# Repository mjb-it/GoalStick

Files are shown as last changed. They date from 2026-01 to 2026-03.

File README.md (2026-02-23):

# GoalStick

An NHL goal celebration system that triggers LED light shows when your favorite team scores. The system consists of three components:

- **Raspberry Pi Service** (Python) - Monitors NHL games and detects goals
- **Android App** (Kotlin) - Companion app for configuration via Bluetooth
- **ESP32 Firmware** (Arduino/C++) - Controls WS2812B LED strip animations

## Repository Structure

```
GoalStick/
├── PythonSrc/       # Raspberry Pi Python service
├── Android/         # Android companion app
├── ESP32/           # ESP32 LED controller firmware
├── Makefile         # Build and test automation
└── README.md
```

---

# Raspberry Pi Service (Python)

The core service that monitors NHL games and communicates with the ESP32 to trigger celebrations.

## Requirements

- Raspberry Pi Zero 2 W (or any Pi with GPIO)
- Python 3.9+
- Serial connection to ESP32

## Installation

```bash
cd PythonSrc
pip install -e .
```

Or using Make:
```bash
make python-install
```

## Usage

```bash
cd PythonSrc

# Start the goal monitoring service
python main.py

# Set your team (persists across reboots)
python main.py --team WSH

# Show currently configured team
python main.py --show-team

# Enter Bluetooth pairing mode
python main.py --pair
```

## Testing

```bash
# Run unit tests (69 tests)
make python-test

# Run with coverage report
make python-test-cov
```

## Configuration Options

| Parameter | Type | Default | Description |
|---|---|---|---|
| `team_abbr` | str | "WSH" | NHL team abbreviation |
| `check_interval` | float | 2.0 | Seconds between goal checks during live games |
| `daily_check_hour` | int | 8 | Hour (24-hour format) to check daily schedule |
| `pre_game_wake_minutes` | int | 5 | Minutes before game to wake up |
| `serial_port` | str | "/dev/serial0" | Serial port for ESP32 communication |
| `serial_baud_rate` | int | 115200 | Baud rate for serial communication |
| `pairing_button_pin` | int | 17 | BCM GPIO pin for pairing button |
| `esp32_reset_pin` | int | 27 | BCM GPIO pin connected to ESP32 EN |

## Dependencies

- `nhlpy` - NHL API client
- `python-dateutil` - Date parsing utilities
- `pyserial` - Serial communication with ESP32
- `RPi.GPIO` - GPIO control (optional, for button/reset)

---

# Android App (Kotlin)

Companion app for configuring the GoalStick via Bluetooth.

## Requirements

- Android Studio Hedgehog (2023.1.1) or newer
- Android SDK 34
- Java 17 (for command-line builds)

## Features

- Bluetooth device discovery and pairing
- WiFi credential configuration
- NHL team selection (all 32 teams)
- Send configuration to Raspberry Pi

## Building

### Using Android Studio (Recommended)

1. Open `Android/` folder in Android Studio
2. Sync Gradle files
3. Build → Build Bundle(s) / APK(s) → Build APK(s)

### Using Command Line

```bash
# Requires Android SDK and Java 17
make android-build

# APK location:
# Android/app/build/outputs/apk/debug/app-debug.apk
```

### Installing on Device

```bash
# With device connected via USB
make android-install

# Or manually:
adb install Android/app/build/outputs/apk/debug/app-debug.apk
```

## Project Structure

```
Android/
├── app/src/main/
│   ├── java/com/goalstick/android/
│   │   ├── MainActivity.kt           # Main UI
│   │   ├── bluetooth/BluetoothManager.kt  # BT connection
│   │   ├── data/ConfigurationData.kt # Team data
│   │   └── ui/                        # UI components
│   ├── res/layout/                    # XML layouts
│   └── AndroidManifest.xml
├── build.gradle
└── settings.gradle
```

---

# ESP32 Firmware (Arduino)

Controls the WS2812B LED strip and receives commands from the Raspberry Pi.

## Requirements

- ESP32 development board
- Arduino IDE or PlatformIO
- FastLED library

## Building

1. Open `ESP32/hockey_stick_light_controller.ino` in Arduino IDE
2. Install FastLED library (Sketch → Include Library → Manage Libraries)
3. Select board: ESP32 Dev Module
4. Upload to ESP32

## Pin Configuration

| Pin | Function |
|-----|---|
| GPIO 4 | LED Data Out |
| GPIO 16 (RX2) | Serial RX from Raspberry Pi |
| GPIO 17 (TX2) | Serial TX to Raspberry Pi |

## Serial Protocol

The ESP32 listens on Serial2 at 115200 baud:

| Command | Format | Description |
|---|---|---|
| Celebrate | `C:RRGGBB,RRGGBB,...\n` | Trigger goal animation with hex colors |
| Idle | `I\n` | Stop animation and clear strip |
| Ping | `P\n` | Health check, responds with `PONG\n` |

Example: `C:FFFFFF,002D62,E51937\n` (Washington Capitals colors)

---

# Hardware Setup

## Components

- **Raspberry Pi Zero 2 W** - Runs the Python service
- **ESP32** - Controls LED strip via serial
- **WS2812B LED Strip** - 300+ addressable LEDs
- **5V Power Supply** - Minimum 2A (more for full strip)
- **Momentary Push Button** - For Bluetooth pairing

## Wiring Diagram

### Raspberry Pi ↔ ESP32

| Raspberry Pi | ESP32 | Purpose |
|---|---|---|
| GPIO 14 (TX) | GPIO 16 (RX2) | Serial data |
| GPIO 27 | EN | ESP32 reset (optional) |
| GND | GND | Common ground |

### ESP32 ↔ LED Strip

| ESP32 | LED Strip | Purpose |
|---|---|---|
| GPIO 4 | Data In (via 470Ω resistor) | LED control |
| VIN | 5V | Power |
| GND | GND | Ground |

### Pairing Button

| Raspberry Pi | Button |
|---|---|
| GPIO 17 | Pin 1 (uses internal pull-up) |
| GND | Pin 2 |

Press and hold for 3 seconds to enter pairing mode.

## Hardware Protection

- **1000µF Capacitor** - Across 5V/GND rails near power input
- **470Ω Resistor** - Between ESP32 GPIO 4 and LED Data In
- **Logic Level Shifter** (optional) - 74AHCT125 for long cable runs

---

# Build & Deployment

For hands-free installation and automated deployment instructions, see **[DEPLOYMENT.md](DEPLOYMENT.md)**.

Quick build commands:

```bash
make help          # Show all available targets
make all           # Build everything
make test          # Run all tests
make clean         # Clean all artifacts
```

---

# NHL Team Abbreviations

| Conference | Teams |
|---|---|
| Eastern | BOS, BUF, CAR, CBJ, DET, FLA, MTL, NJD, NYI, NYR, OTT, PHI, PIT, TBL, TOR, WSH |
| Western | ANA, ARI, CGY, CHI, COL, DAL, EDM, LAK, MIN, NSH, SEA, SJS, STL, VAN, VGK, WPG |

---

# License

This project is licensed under the MIT License - see the [LICENSE](LICENSE) file for details.

# Contributing

1. Fork the repository
2. Create a feature branch
3. Make your changes
4. Add tests if applicable
5. Submit a pull request

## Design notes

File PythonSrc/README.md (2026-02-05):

# GoalStick Python Service

Python service for monitoring NHL games and triggering LED celebrations on a Raspberry Pi.

## Features

- Monitors NHL API for live game scores
- Triggers LED celebration when your team scores
- Bluetooth configuration via Android app
- Auto-updates code and system security patches
- Factory reset via 10-second button hold

## Hardware Requirements

- Raspberry Pi Zero 2W (or any Pi with WiFi/Bluetooth)
- ESP32 for LED control (connected via UART)
- Momentary push button (for pairing/reset)
- WS2812B LED strip

## Wiring

### Pi Zero 2W → ESP32

| Pi Zero 2W Pin | Function | ESP32 Pin |
|---|---|---|
| GPIO 14 (TXD)  | UART TX  | GPIO 16 (RX2) |
| GPIO 15 (RXD)  | UART RX  | GPIO 17 (TX2) |
| GPIO 27 | Reset | EN |
| GND | Ground | GND |
| 5V | Power | VIN |

### ESP32 → LED Strip

| ESP32 Pin | Function | LED Strip |
|---|---|---|
| GPIO 4 | Data | DIN |
| GND | Ground | GND |
| VIN (5V)  | Power | 5V (or external PSU for long strips) |

### Button (Pairing/Reset)

| Pi Zero 2W Pin | Function |
|---|---|
| GPIO 17 | Button (one side) |
| GND | Button (other side) |

- **Hold 3 seconds**: Enter Bluetooth pairing mode
- **Hold 10 seconds**: Factory reset (clears WiFi, Bluetooth, config)

### Status Indicator (via LED Strip)

The LED strip is used for status indication. No separate status LED needed.

**LED Strip States** (off during normal operation):

| Color | Pattern | Meaning |
|---|---|---|
| Off | - | Normal operation |
| Yellow | Solid | Booting |
| Magenta | Slow blink | WiFi not configured (needs setup) |
| Blue | Slow blink | Bluetooth pairing mode |
| Cyan | Slow blink | Updating |
| Red | Solid | Error |
| Red | Fast blink | No network connectivity |

## Installation

### Option 1: Pre-Built Image (Easiest)

Use the first-boot script to create a ready-to-distribute image:

1. Flash **Raspberry Pi OS Lite 64-bit** with Raspberry Pi Imager
2. In imager settings (⚙️), configure:
   - Enable SSH
   - Set hostname to `goalstick`
   - Configure your WiFi (temporary, will be wiped)
   - Set username/password
3. After flashing, mount the boot partition and copy the setup script:
   ```bash
   cp scripts/firstboot-setup.sh /Volumes/bootfs/firstboot-setup.sh
   ```
4. Edit `/Volumes/bootfs/cmdline.txt` and add to the **end of the existing line**:
   ```
    systemd.run=/boot/firmware/firstboot-setup.sh systemd.run_success_action=reboot
   ```
5. Eject and boot the Pi
6. Wait ~10 minutes for setup to complete (LED will be yellow, then cyan during update)
7. Pi will reboot with **WiFi wiped** - use the Android app to configure

> **Note**: The first-boot script wipes all WiFi credentials after installation,
> making the image safe to distribute without exposing your network password.

### Option 2: Manual Installation

#### Prerequisites

Install system dependencies (required for D-Bus and GPIO):

```bash
sudo apt-get update
sudo apt-get install -y python3-gi python3-dbus bluetooth bluez
```

Enable UART for ESP32 communication:

```bash
# Add to /boot/firmware/config.txt:
echo "enable_uart=1" | sudo tee -a /boot/firmware/config.txt
sudo reboot
```

Enable Bluetooth compatibility mode for SPP:

```bash
sudo sed -i 's/ExecStart=\/usr\/libexec\/bluetooth\/bluetoothd/ExecStart=\/usr\/libexec\/bluetooth\/bluetoothd -C/' /lib/systemd/system/bluetooth.service
sudo systemctl daemon-reload
sudo systemctl restart bluetooth
```

Disable Bluetooth audio plugins (prevents Android from treating GoalStick as a headset):

```bash
sudo tee -a /etc/bluetooth/main.conf << 'EOF'

# Disable audio plugins - GoalStick is not an audio device
[General]
DisablePlugins = a2dp,avrcp
EOF
sudo systemctl restart bluetooth
```

#### Quick Deploy (Production)

Clone and deploy to `/opt/goalstick`:

```bash
git clone https://github.com/mjb-it/GoalStick.git ~/GoalStick
cd ~/GoalStick
make deploy
```

This will:
1. Copy files to `/opt/goalstick`
2. Create virtual environment with system packages
3. Install Python dependencies
4. Set up and start the systemd service

### Development Install

For development on the Pi:

```bash
git clone https://github.com/mjb-it/GoalStick.git ~/GoalStick
cd ~/GoalStick
python3 -m venv .venv --system-site-packages
source .venv/bin/activate
pip install -e "PythonSrc[dev]"
make service-install
```

## Configuration

Configuration is stored in `/etc/goalstick/config.json`:

```json
{
  "team_abbr": "WSH"
}
```

Configure via the Android app or manually edit the file.

## Service Management

```bash
# Check status
make service-status

# View logs
make service-logs

# Restart service
sudo systemctl restart goalstick

# Stop service
sudo systemctl stop goalstick

# Uninstall service
make service-uninstall
```

## File Locations

| Path | Description |
|---|---|
| `/opt/goalstick` | Application code (production) |
| `/etc/goalstick/config.json` | Configuration file |
| `/var/log/goalstick/goalstick.log` | Log file (rotates weekly) |

## Manual Usage

For testing without the service:

```bash
cd /opt/goalstick/PythonSrc
source ../.venv/bin/activate

# Normal operation (monitors games)
python main.py

# Specify team
python main.py --team WSH

# Enter pairing mode
python main.py --pair

# Show current team
python main.py --show-team
```

## Auto-Updates

The service automatically:
- **Daily (8 AM)**: Checks for code updates via `git pull`
- **Weekly (Sundays)**: Runs system security updates

## Read-Only Filesystem (Optional)

For production devices, you can enable a read-only root filesystem to protect the SD card from corruption due to power loss:

```bash
make deploy-readonly
sudo reboot
```

This sets up:
- **Overlay filesystem** - Root is read-only, changes go to RAM
- **Persistent storage** - Config, WiFi, and Bluetooth survive reboots
- **tmpfs logs** - Logs are in RAM (lost on reboot, but viewable via `journalctl`)

### Persistent Data Locations

| Data | Location |
|---|---|
| GoalStick config | `/persistent/goalstick/` |
| Bluetooth pairings | `/persistent/bluetooth/` |
| WiFi credentials | `/persistent/wpa_supplicant/` |

### Helper Commands

```bash
goalstick-status  # Check if overlay is active
goalstick-rw      # Instructions to disable overlay for manual changes
goalstick-ro      # Re-enable overlay after changes
```

### How Updates Work with Read-Only Root

When updates are available:
1. Service detects update, disables overlay, reboots
2. On reboot (read-write mode), applies update, re-enables overlay, reboots
3. On final reboot, system is back to read-only with updates applied

## Troubleshooting

### Service won't start

```bash
# Check status and recent logs
sudo systemctl status goalstick
sudo journalctl -u goalstick -n 50

# Reset failed state
sudo systemctl reset-failed goalstick
sudo systemctl start goalstick
```

### Bluetooth pairing issues

```bash
# Check Bluetooth status
sudo systemctl status bluetooth
bluetoothctl show

# Restart Bluetooth
sudo systemctl restart bluetooth
```

### ESP32 not responding

The service will attempt to reset the ESP32 automatically. Check wiring if issues persist.

## License

MIT

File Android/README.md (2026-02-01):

# GoalStick Android App

Android companion app for the GoalStick NHL goal celebration light system.

## Features

- Monitor NHL games in real-time
- Configure team settings
- Control ESP32 LED light strips
- View game statistics

## Requirements

- Android Studio Hedgehog (2023.1.1) or newer
- Android SDK 34
- Kotlin 1.9+

## Project Structure

```
Android/
├── app/
│   ├── src/main/
│   │   ├── java/com/goalstick/android/  # Kotlin source
│   │   ├── res/                          # Resources
│   │   └── AndroidManifest.xml
│   └── build.gradle
├── build.gradle
├── settings.gradle
└── README.md
```

## Building

1. Open the `Android` directory in Android Studio
2. Sync Gradle files
3. Build → Make Project (Ctrl+F9)

## Running

1. Connect an Android device or start an emulator
2. Run → Run 'app' (Shift+F10)

## Architecture

- **Language**: Kotlin
- **UI**: XML layouts with Material3 components
- **Min SDK**: 24 (Android 7.0)
- **Target SDK**: 34 (Android 14)

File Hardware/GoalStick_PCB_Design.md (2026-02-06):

# GoalStick PCB Design

Carrier board for Pi Zero 2W + ESP32 DevKit to mount on hockey stick.

## Components

| Component | Footprint | Notes |
|---|---|---|
| Pi Zero 2W | 2x20 pin header (2.54mm) | 65mm × 30mm |
| ESP32 DevKit V1 | 2x15 pin header (2.54mm) | ~51mm × 28mm |
| Tactile Button | 6mm × 6mm through-hole | Pairing/Reset |
| JST-XH 3-pin | 2.5mm pitch | LED strip connector (5V, GND, Data) |
| 10kΩ Resistor | 0805 SMD or through-hole | Button pull-up (optional, Pi has internal) |

## Schematic

```
                    Pi Zero 2W                          ESP32 DevKit V1
                 ┌──────────────┐                    ┌──────────────────┐
                 │              │                    │                  │
    5V Power ────┤ 5V      3.3V ├                    │ VIN          3V3 │
                 │              │                    │                  │
         GND ────┤ GND      GND ├────────────────────┤ GND          GND ├──── GND
                 │              │                    │                  │
                 │ GPIO14 (TX) ─┼────────────────────┤► GPIO16 (RX2)    │
                 │              │                    │                  │
                 │ GPIO15 (RX) ◄┼────────────────────┼─ GPIO17 (TX2)    │
                 │              │                    │                  │
                 │ GPIO27 ──────┼────────────────────┤► EN (Reset)      │
                 │              │                    │                  │
                 │ GPIO17 ◄─────┼── Button ── GND    │ GPIO4 ───────────┼──── LED Data
                 │              │                    │                  │
                 └──────────────┘                    └──────────────────┘

    LED Strip Connector (JST-XH 3-pin):
    ┌─────┐
    │ 5V  │──── From Pi 5V or external PSU
    │ GND │──── Common ground
    │ DIN │──── From ESP32 GPIO4
    └─────┘
```

## PCB Layout Suggestions

### Board Dimensions
- **Width**: ~80mm (fits hockey stick blade)
- **Height**: ~100mm (stacked vertically: Pi on top, ESP32 below)
- **Mounting holes**: 4x M3 (3.2mm) at corners

### Layout (Top View)
```
    ┌────────────────────────────────────┐
    │  ○                              ○  │  ← Mounting holes
    │                                    │
    │    ┌──────────────────────────┐    │
    │    │     Pi Zero 2W           │    │
    │    │     (header socket)      │    │
    │    └──────────────────────────┘    │
    │                                    │
    │    ┌──────────────────────────┐    │
    │    │     ESP32 DevKit         │    │
    │    │     (header socket)      │    │
    │    └──────────────────────────┘    │
    │                                    │
    │   [BTN]              [JST LED]     │
    │                                    │
    │  ○                              ○  │
    └────────────────────────────────────┘
```

## KiCad Project

Project files are in `Hardware/KiCad/GoalStick.kicad_pro`

### Opening the Project
1. Open KiCad (in Applications)
2. File → Open Project → select `GoalStick.kicad_pro`

### Adding Components to Schematic
Open the schematic editor and add these symbols:

| Symbol | Library | Notes |
|---|---|---|
| Conn_02x20_Odd_Even | Connector_Generic | Pi Zero header |
| Conn_01x15 (x2) | Connector_Generic | ESP32 headers |
| SW_Push | Switch | Tactile button |
| Conn_01x03 | Connector_Generic | LED strip JST |

### Wiring in Schematic
1. Place components
2. Use 'W' key to wire
3. Add power symbols: VCC, +5V, GND
4. Add net labels for clarity (UART_TX, UART_RX, etc.)

### Assigning Footprints
1. Tools → Assign Footprints
2. Suggested footprints:
   - Pi header: `Connector_PinSocket_2.54mm:PinSocket_2x20_P2.54mm_Vertical`
   - ESP32 headers: `Connector_PinSocket_2.54mm:PinSocket_1x15_P2.54mm_Vertical`
   - Button: `Button_Switch_THT:SW_PUSH_6mm`
   - JST: `Connector_JST:JST_XH_B3B-XH-A_1x03_P2.50mm_Vertical`

### Creating PCB
1. Tools → Update PCB from Schematic
2. Arrange components
3. Draw board outline on Edge.Cuts layer
4. Route traces (or use autorouter)
5. Run DRC (Inspect → Design Rules Checker)

### Ordering from JLCPCB
1. File → Fabrication Outputs → Gerbers
2. Upload ZIP to jlcpcb.com
3. Default settings work (~$5 for 5 boards)

## Power Considerations

- Pi Zero 2W draws ~200-400mA
- ESP32 draws ~80-240mA
- WS2812B LEDs: ~60mA per LED at full white
- **For short strips (<30 LEDs)**: Power from Pi 5V is fine
- **For longer strips**: Use external 5V PSU, share GND only

## Bill of Materials

| Qty | Part | Example Part Number | Est. Cost |
|-----|---|---|---|
| 1 | 2x20 Female Header 2.54mm | - | $1 |
| 2 | 1x15 Female Header 2.54mm | - | $1 |
| 1 | 6mm Tactile Switch | - | $0.10 |
| 1 | JST-XH 3-pin Right Angle | B3B-XH-A | $0.20 |
| 4 | M3 Standoffs + Screws | - | $1 |
| 1 | PCB (JLCPCB 5pcs) | - | $5 |

**Total: ~$8-10** (plus shipping)

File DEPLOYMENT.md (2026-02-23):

# GoalStick Deployment Guide

This guide covers automated deployment and hands-free installation of the GoalStick system.

---

## Build System

Use the Makefile for all build and test operations:

```bash
make help
```

## Available Targets

### Android Targets

| Target | Description |
|---|---|
| `make android-build` | Build Android debug APK |
| `make android-release` | Build Android release APK |
| `make android-install` | Install APK to connected device |
| `make android-clean` | Clean Android build artifacts |

### Python Targets

| Target | Description |
|---|---|
| `make python-venv` | Create virtual environment (if needed) |
| `make python-test` | Run Python unit tests |
| `make python-test-cov` | Run tests with coverage report |
| `make python-install` | Install Python package in dev mode |
| `make python-clean` | Clean Python build artifacts |

### Deployment Targets (run on Pi)

| Target | Description |
|---|---|
| `make deploy` | Deploy to /opt/goalstick and install service |
| `make deploy-readonly` | Deploy + set up read-only filesystem (reboot required) |
| `make service-install` | Install systemd service from current directory |
| `make service-uninstall` | Remove systemd service |
| `make service-status` | Check service status |
| `make service-logs` | Tail the service logs |

### Combined Targets

| Target | Description |
|---|---|
| `make all` | Build everything |
| `make test` | Run all tests |
| `make clean` | Clean all artifacts |

---

## Raspberry Pi Setup

### SD Card Preparation

1. Flash Raspberry Pi OS Lite to an SD card
2. Mount the boot partition and copy the following files from this repo:
   - `config.txt` - Enables USB gadget mode
   - `cmdline.txt` - Loads USB Ethernet module
   - `wpa_supplicant.conf` - WiFi credentials (edit with your network)

3. Create an empty `ssh` file on the boot partition to enable SSH:
   ```bash
   touch /Volumes/bootfs/ssh
   ```

### WiFi Configuration

For newer Raspberry Pi OS versions using cloud-init, edit `network-config` on the boot partition:

```yaml
network:
  version: 2

  wifis:
    wlan0:
      dhcp4: true
      optional: false
      access-points:
        "YourWiFiSSID":
          password: "YourWiFiPassword"
```

### USB Ethernet Gadget Mode

If WiFi isn't working, you can access the Pi directly over USB:

1. Ensure `config.txt` contains under `[all]`:
   ```
   dtoverlay=dwc2
   ```

2. Ensure `cmdline.txt` contains:
   ```
   modules-load=dwc2,g_ether
   ```

3. Connect the Pi's **USB** port (not PWR) to your computer

4. SSH to the Pi:
   ```bash
   ssh pi@raspberrypi.local
   ```

---

## Python Service Installation

### Quick Deploy (Recommended)

On the Raspberry Pi, clone the repo and run the deploy target:

```bash
git clone https://github.com/yourusername/GoalStick.git
cd GoalStick
make deploy
```

This will:
- Install to `/opt/goalstick`
- Create a virtual environment
- Install the systemd service
- Start the service automatically

### Manual Installation

```bash
# Clone the repository
git clone https://github.com/yourusername/GoalStick.git
cd GoalStick

# Create virtual environment and install
make python-venv
make python-install

# Or manually:
cd PythonSrc
pip install -e .
```

### Service Management

```bash
# Install service from current directory
make service-install

# Check status
make service-status

# View logs
make service-logs

# Remove service
make service-uninstall
```

### Read-Only Filesystem (Optional)

For production deployments, enable read-only filesystem to prevent SD card corruption:

```bash
make deploy-readonly
```

This requires a reboot to take effect.

### File Locations

| Path | Description |
|---|---|
| `/opt/goalstick` | Installation directory |
| `/etc/goalstick/config.json` | Configuration file |
| `/var/log/goalstick/goalstick.log` | Log file |

---

## ESP32 Firmware

### XIAO ESP32C3

1. Install the **esp32 by Espressif Systems** board package in Arduino IDE
2. Select **Tools → Board → esp32 → XIAO_ESP32C3**
3. Open `ESP32/hockey_stick_light_controller_copy_20260131123701/hockey_stick_light_controller/hockey_stick_light_controller.ino`
4. Upload to the board

### Pin Configuration (XIAO ESP32C3)

| Pin | Function |
|-----|---|
| D10 (GPIO10) | LED Data Out |
| D7 (GPIO20) | Serial RX from Raspberry Pi |
| D6 (GPIO21) | Serial TX to Raspberry Pi |

### Wiring: Raspberry Pi ↔ XIAO ESP32C3

| Raspberry Pi | XIAO ESP32C3 | Purpose |
|---|---|---|
| GPIO 14 (TX) | D7 (RX) | Serial data to ESP32 |
| GPIO 15 (RX) | D6 (TX) | Serial data from ESP32 |
| GND | GND | Common ground |

---

## Android App

### Building

```bash
make android-build
```

### Installing

```bash
# With device connected via USB
make android-install
```

APK location: `Android/app/build/outputs/apk/debug/app-debug.apk`

---

## Troubleshooting

### Pi not connecting to WiFi
- Verify `network-config` YAML syntax (spaces, not tabs)
- Check that SSID and password are correct
- Try USB Ethernet gadget mode for direct access

### ESP32 not responding
- Check serial connections (TX→RX, RX→TX)
- Verify baud rate is 115200
- Test with USB Serial Monitor first

### Bluetooth pairing fails
- Ensure Pi Bluetooth is enabled: `sudo systemctl start bluetooth`
- Check that the Android app has Bluetooth permissions
- Hold pairing button for 3+ seconds

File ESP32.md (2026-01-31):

# **ESP32 Universal LED Controller (NHL Art Piece)**

This firmware transforms the ESP32 into a dedicated serial-controlled LED driver. It is designed to sit behind a high-level controller (Raspberry Pi Zero 2 W) and execute high-performance, non-blocking animations for 300+ WS2812B LEDs.

## **1\. Physical Interface**

### **Wiring Pinout**

| ESP32 Pin | Label | Connection | Purpose |
| :---- | :---- | :---- | :---- |
| **VIN** | 5V | External 5V (+) | Power input (Shared with Pi/Strip) |
| **GND** | GND | External 5V (-) | **Common Ground** (Required) |
| **GPIO 4** | D4 | LED Data In (via 470Ω) | Data Signal to LED Strip |
| **GPIO 16** | RX2 | Pi TX (GPIO 14) | Serial Command Input |

Export to Sheets

### **Hardware Protection**

* **1000µF Capacitor:** Must be placed across the 5V/GND rails near the power input.  
* **470Ω Resistor:** Must be placed in-line between GPIO 4 and the LED `Data In` pad.  
* **Logic Level Shifter:** Recommended (74AHCT125) to boost 3.3V logic to 5V for reliable signal over long distances.

## **2\. Serial Protocol Specification**

The ESP32 listens on **Hardware Serial 2** (mapped to GPIO 16\) with the following configuration:

* **Baud Rate:** `115200`  
* **Data Bits:** `8`  
* **Parity:** `None`  
* **Stop Bits:** `1`

### **Command Set**

| Command | Format | Description |
| :---- | :---- | :---- |
| **Celebration** | `C:RRGGBB,RRGGBB...` | Triggers the goal animation using the provided hex colors. |
| **Idle** | `I` | Stops any current animation and clears the strip. |
| **Ping** | `P` | Health check. ESP32 responds with `PONG\\n`. |

Export to Sheets

#### **Command Example: Washington Capitals**

To trigger a celebration for the Capitals, the Pi sends: `C:FFFFFF,002D62,E51937\n`

* **Prefix:** `C:` tells the ESP32 a color array follows.  
* **Values:** Up to 5 Hexadecimal strings (6 characters, no `#`), comma-separated.  
* **Terminator:** Line feed (`\n`) or carriage return is required to process.

## **3\. Logic & Behavior**

### **Goal Celebration Sequence**

When a valid `C:` command is received:

1. **Impact Phase:** The entire strip flashes the first color of the array 3 times (400ms intervals).  
2. **Chase Phase:** A repeating pattern is generated. Every 10 LEDs represent one color from the array. This pattern "chases" forward at \~50 FPS.  
3. **Timeout:** The animation automatically terminates and clears the strip after **10 seconds**.

### **Multi-Tasking (Non-Blocking)**

The ESP32 uses a `millis()`\-based state machine. This allows the device to:

* Maintain fluid 60Hz animations.  
* Instantly receive an `I` (Idle) command to cancel a celebration (useful for overturned goals).  
* Switch teams mid-animation if a new `C:` command arrives.

## **4\. Troubleshooting**

* **No Response:** Verify the Raspberry Pi and ESP32 share a **Common Ground**.  
* **Flickering LEDs:** Ensure the 5V power supply has enough amperage (min 2A for breadboard testing).  
* **Garbage Serial Output:** Ensure the Baud Rate on the Pi matches exactly `115200`.  
* **Wrong Colors:** If Red and Green are swapped, change the LED type in the firmware from `NEO_GRB` to `NEO_RGB`.

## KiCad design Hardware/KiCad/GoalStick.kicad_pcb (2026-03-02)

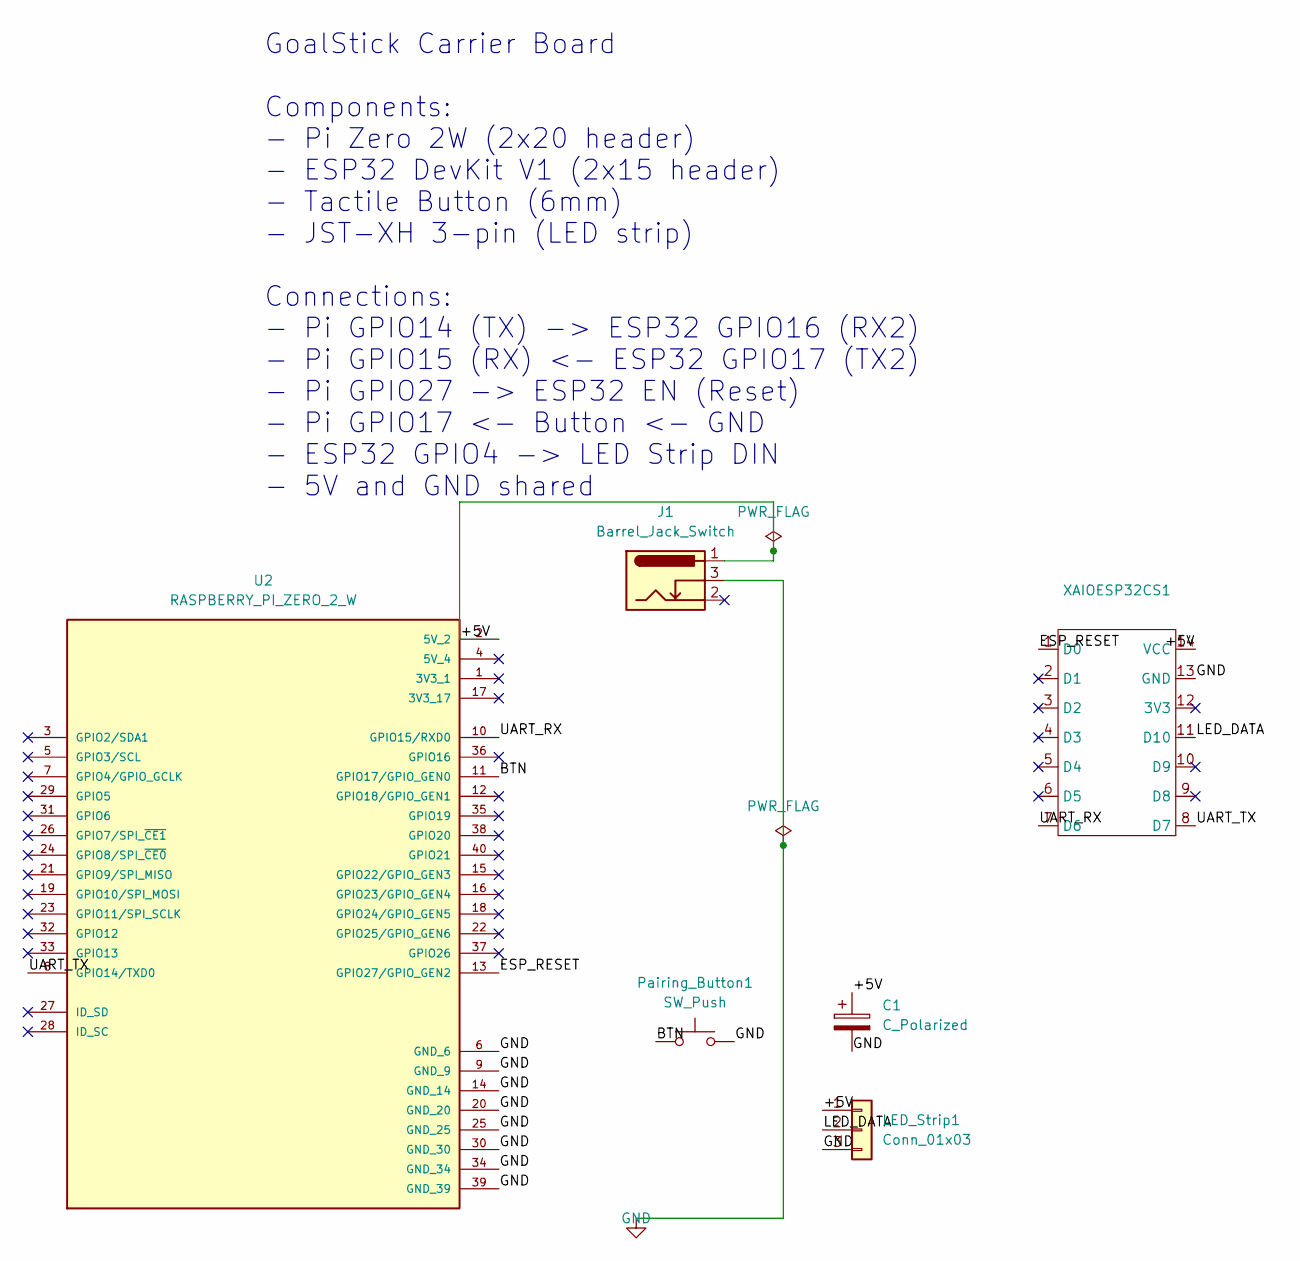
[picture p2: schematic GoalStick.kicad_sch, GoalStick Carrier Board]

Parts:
C1: C_Polarized; CP_Radial_D8.0mm_P3.50mm
J1: Barrel_Jack_Switch; BarrelJack_Horizontal
LED_Strip1: Conn_01x03; JST_XH_B3B-XH-A_1x03_P2.50mm_Vertical
Pairing_Button1: SW_Push; SW_PUSH_6mm
U2: RASPBERRY_PI_ZERO_2_W; MODULE_RASPBERRY_PI_ZERO_2_W; PARTREV April 2024
XAIOESP32CS1: XIAO-ESP32-C3-DIP

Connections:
/+5V: C1.1, J1.1, LED_Strip1.1, U2.2 (5V_2), XAIOESP32CS1.14 (VCC)
/BTN: Pairing_Button1.1, U2.11 (GPIO17/GPIO_GEN0)
/ESP_RESET: U2.13 (GPIO27/GPIO_GEN2), XAIOESP32CS1.1 (D0)
/LED_DATA: LED_Strip1.2, XAIOESP32CS1.11 (D10)
/UART_RX: U2.10 (GPIO15/RXD0), XAIOESP32CS1.7 (D6)
/UART_TX: U2.8 (GPIO14/TXD0), XAIOESP32CS1.8 (D7)
GND: C1.2, J1.3, LED_Strip1.3, Pairing_Button1.2, U2.6 (GND_6), U2.9 (GND_9), U2.14 (GND_14), U2.20 (GND_20), U2.25 (GND_25), U2.30 (GND_30), U2.34 (GND_34), U2.39 (GND_39), XAIOESP32CS1.13 (GND)

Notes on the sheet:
GoalStick Carrier Board Components: - Pi Zero 2W (2x20 header) - ESP32 DevKit V1 (2x15 header) - Tactile Button (6mm) - JST-XH 3-pin (LED strip) Connections: - Pi GPIO14 (TX) -> ESP32 GPIO16 (RX2) - Pi GPIO15 (RX) <- ESP32 GPIO17 (TX2) - Pi GPIO27 -> ESP32 EN (Reset) - Pi GPIO17 <- Button <- GND - 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

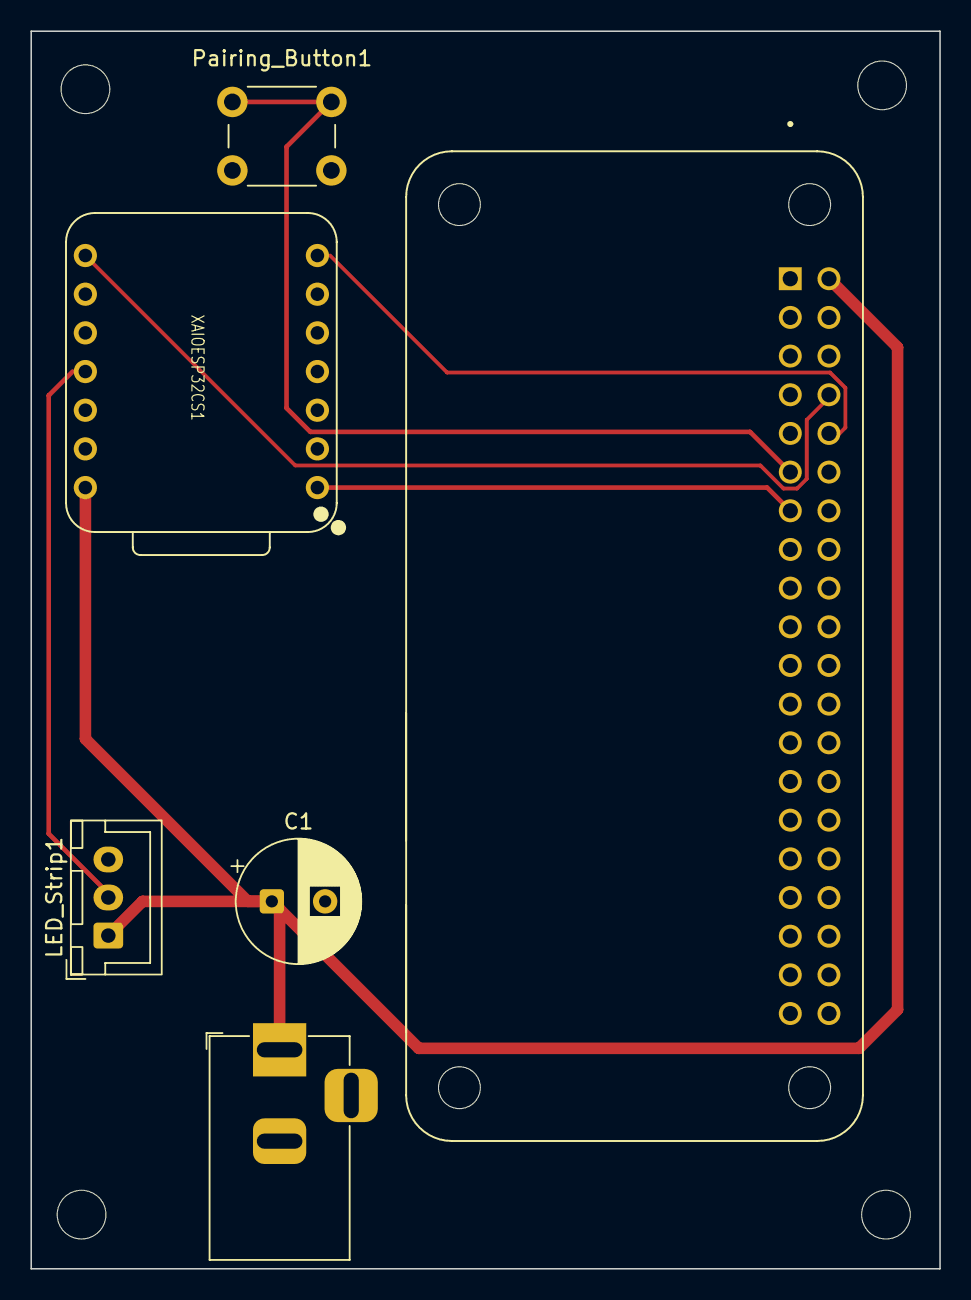
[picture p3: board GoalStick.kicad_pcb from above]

Board: 2 copper layers, 59.7 x 81.3 mm, 7 parts (0 on the bottom side), 7 nets.

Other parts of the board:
Mount: MountingHole_3.2mm_M3

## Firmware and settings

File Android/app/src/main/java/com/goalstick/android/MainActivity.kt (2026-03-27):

package com.goalstick.android

import android.Manifest
import android.bluetooth.BluetoothAdapter
import android.bluetooth.BluetoothDevice
import android.content.BroadcastReceiver
import android.content.Context
import android.content.Intent
import android.content.IntentFilter
import android.content.pm.PackageManager
import android.os.Build
import android.os.Bundle
import android.view.View
import android.widget.ArrayAdapter
import android.widget.Button
import android.widget.ProgressBar
import android.widget.SeekBar
import android.widget.Spinner
import android.widget.TextView
import android.widget.Toast
import androidx.activity.result.contract.ActivityResultContracts
import androidx.appcompat.app.AppCompatActivity
import androidx.core.app.ActivityCompat
import androidx.lifecycle.ViewModelProvider
import androidx.lifecycle.lifecycleScope
import androidx.recyclerview.widget.LinearLayoutManager
import androidx.recyclerview.widget.RecyclerView
import com.goalstick.android.bluetooth.BluetoothManager
import com.goalstick.android.data.TeamData
import com.goalstick.android.ui.DeviceAdapter
import com.goalstick.android.ui.MainViewModel
import com.goalstick.android.wifi.WifiHelper
import com.google.android.material.textfield.TextInputEditText
import kotlinx.coroutines.flow.collectLatest
import kotlinx.coroutines.launch

class MainActivity : AppCompatActivity() {
    
    private lateinit var viewModel: MainViewModel
    private lateinit var deviceAdapter: DeviceAdapter
    
    // Discovery UI
    private lateinit var statusText: TextView
    private lateinit var ipAddressText: TextView
    private lateinit var scanButton: Button
    private lateinit var devicesRecyclerView: RecyclerView
    private lateinit var discoveryProgressBar: ProgressBar
    
    // Configuration UI
    private lateinit var configLayout: View
    private lateinit var wifiSsidInput: TextInputEditText
    private lateinit var wifiPasswordInput: TextInputEditText
    private lateinit var teamSpinner: Spinner
    private lateinit var delaySeekBar: SeekBar
    private lateinit var delayValueText: TextView
    private lateinit var sendConfigButton: Button
    private lateinit var testGoalButton: Button
    private lateinit var configProgressBar: ProgressBar
    
    // WiFi helper
    private lateinit var wifiHelper: WifiHelper
    
    private val bluetoothReceiver = object : BroadcastReceiver() {
        override fun onReceive(context: Context, intent: Intent) {
            when (intent.action) {
                BluetoothDevice.ACTION_FOUND -> {
                    val device: BluetoothDevice? = intent.getParcelableExtra(BluetoothDevice.EXTRA_DEVICE)
                    device?.let { viewModel.bluetoothManager.addDiscoveredDevice(it) }
                }
                BluetoothAdapter.ACTION_DISCOVERY_FINISHED -> {
                    discoveryProgressBar.visibility = View.GONE
                    scanButton.isEnabled = true
                }
            }
        }
    }
    
    private val permissionLauncher = registerForActivityResult(
        ActivityResultContracts.RequestMultiplePermissions()
    ) { permissions ->
        val allGranted = permissions.all { it.value }
        if (allGranted) {
            startScan()
        } else {
            Toast.makeText(this, "Bluetooth permissions required", Toast.LENGTH_LONG).show()
        }
    }
    
    override fun onCreate(savedInstanceState: Bundle?) {
        super.onCreate(savedInstanceState)
        setContentView(R.layout.activity_main)
        
        viewModel = ViewModelProvider(this)[MainViewModel::class.java]
        wifiHelper = WifiHelper(this)
        
        setupViews()
        setupRecyclerView()
        setupTeamSpinner()
        observeViewModel()
        registerBluetoothReceiver()
        
        // Auto-connect to GoalStick if paired, or prompt user
        autoConnectOrPrompt()
    }
    
    private var goalStickDevice: BluetoothDevice? = null
    
    private fun autoConnectOrPrompt() {
        val pairedDevices = viewModel.bluetoothManager.getPairedDevices()
        goalStickDevice = pairedDevices.find { device ->
            if (ActivityCompat.checkSelfPermission(this, Manifest.permission.BLUETOOTH_CONNECT)
                == PackageManager.PERMISSION_GRANTED) {
                device.name?.contains("goalstick", ignoreCase = true) == true ||
                device.name?.contains("goalpi", ignoreCase = true) == true
            } else {
                false
            }
        }

        if (goalStickDevice != null) {
            // Found GoalStick - auto-connect
            statusText.text = "Found GoalStick. Connecting..."
            lifecycleScope.launch {
                val connected = viewModel.connect(goalStickDevice!!)
                if (!connected) {
                    // Connection failed - GoalStick is not in pairing mode yet
                    showGoalStickNotReadyPrompt()
                }
            }
        } else {
            // No GoalStick found in paired devices - start scan so user can select it
            statusText.text = "Scanning for GoalStick..."
            checkPermissionsAndScan()
        }
    }

    private fun showGoalStickNotReadyPrompt() {
        statusText.text = "GoalStick is paired but not in configuration mode.\n\nPress and hold the button on GoalStick for 3 seconds to enter pairing mode, then tap Retry."
        scanButton.text = "Retry Connection"
        scanButton.visibility = View.VISIBLE
        scanButton.setOnClickListener {
            goalStickDevice?.let { device ->
                statusText.text = "Connecting..."
                lifecycleScope.launch {
                    val connected = viewModel.connect(device)
                    if (!connected) {
                        showGoalStickNotReadyPrompt()
                    }
                }
            }
        }
    }
    
    private fun setupViews() {
        // Discovery views
        statusText = findViewById(R.id.statusText)
        ipAddressText = findViewById(R.id.ipAddressText)
        scanButton = findViewById(R.id.scanButton)
        devicesRecyclerView = findViewById(R.id.devicesRecyclerView)
        discoveryProgressBar = findViewById(R.id.discoveryProgressBar)
        
        // Configuration views
        configLayout = findViewById(R.id.configLayout)
        wifiSsidInput = findViewById(R.id.wifiSsidInput)
        wifiPasswordInput = findViewById(R.id.wifiPasswordInput)
        teamSpinner = findViewById(R.id.teamSpinner)
        delaySeekBar = findViewById(R.id.delaySeekBar)
        delayValueText = findViewById(R.id.delayValueText)
        sendConfigButton = findViewById(R.id.sendConfigButton)
        testGoalButton = findViewById(R.id.testGoalButton)
        configProgressBar = findViewById(R.id.configProgressBar)
        
        scanButton.setOnClickListener { checkPermissionsAndScan() }
        sendConfigButton.setOnClickListener { sendConfiguration() }
        testGoalButton.setOnClickListener { sendTestGoal() }
        
        delaySeekBar.setOnSeekBarChangeListener(object : SeekBar.OnSeekBarChangeListener {
            override fun onProgressChanged(seekBar: SeekBar?, progress: Int, fromUser: Boolean) {
                delayValueText.text = "${progress}s"
            }
            override fun onStartTrackingTouch(seekBar: SeekBar?) {}
            override fun onStopTrackingTouch(seekBar: SeekBar?) {}
        })
    }
    
    private fun setupRecyclerView() {
        deviceAdapter = DeviceAdapter { device ->
            lifecycleScope.launch {
                viewModel.connect(device)
            }
        }
        devicesRecyclerView.layoutManager = LinearLayoutManager(this)
        devicesRecyclerView.adapter = deviceAdapter
    }
    
    private fun setupTeamSpinner() {
        val teamNames = TeamData.teams.map { "${it.first} - ${it.second}" }
        val adapter = ArrayAdapter(this, R.layout.spinner_item, teamNames)
        adapter.setDropDownViewResource(R.layout.spinner_dropdown_item)
        teamSpinner.adapter = adapter
    }
    
    private fun observeViewModel() {
        lifecycleScope.launch {
            viewModel.bluetoothManager.connectionState.collectLatest { state ->
                when (state) {
                    is BluetoothManager.ConnectionState.Disconnected -> {
                        statusText.text = "Tap scan to find your GoalStick device"
                        configLayout.visibility = View.GONE
                    }
                    is BluetoothManager.ConnectionState.Scanning -> {
                        statusText.text = "Scanning for devices..."
                        discoveryProgressBar.visibility = View.VISIBLE
                    }
                    is BluetoothManager.ConnectionState.Connecting -> {
                        statusText.text = "Connecting..."
                        discoveryProgressBar.visibility = View.VISIBLE
                    }
                    is BluetoothManager.ConnectionState.Connected -> {
                        statusText.text = "Connected! Configure your GoalStick below."
                        discoveryProgressBar.visibility = View.GONE
                        devicesRecyclerView.visibility = View.GONE
                        configLayout.visibility = View.VISIBLE
                        sendConfigButton.isEnabled = true
                        testGoalButton.isEnabled = true
                        
                        // Pre-fill WiFi SSID if connected to WiFi
                        if (wifiSsidInput.text.isNullOrEmpty()) {
                            wifiHelper.getCurrentSsid()?.let { ssid ->
                                wifiSsidInput.setText(ssid)
                            }
                        }
                        
                        // Fetch current config from GoalStick
                        viewModel.fetchConfig()
                    }
                    is BluetoothManager.ConnectionState.Error -> {
                        statusText.text = "Error: ${state.message}"
                        discoveryProgressBar.visibility = View.GONE
                    }
                }
            }
        }
        
        lifecycleScope.launch {
            viewModel.bluetoothManager.discoveredDevices.collectLatest { devices ->
                deviceAdapter.submitList(devices)
                devicesRecyclerView.visibility = if (devices.isNotEmpty()) View.VISIBLE else View.GONE
            }
        }
        
        lifecycleScope.launch {
            viewModel.configSent.collectLatest { sent ->
                if (sent) {
                    Toast.makeText(this@MainActivity, "Configuration sent successfully!", Toast.LENGTH_LONG).show()
                    configProgressBar.visibility = View.GONE
                }
            }
        }
        
        lifecycleScope.launch {
            viewModel.errorMessage.collectLatest { error ->
                error?.let {
                    Toast.makeText(this@MainActivity, it, Toast.LENGTH_LONG).show()
                    configProgressBar.visibility = View.GONE
                    viewModel.clearError()
                }
            }
        }
        
        lifecycleScope.launch {
            viewModel.currentConfig.collectLatest { config ->
                config?.teamAbbr?.let { teamAbbr ->
                    // Find the team in the spinner and select it
                    val teamIndex = TeamData.teams.indexOfFirst { it.first == teamAbbr }
                    if (teamIndex >= 0) {
                        teamSpinner.setSelection(teamIndex)
                    }
                }
                config?.let {
                    delaySeekBar.progress = it.celebrationDelaySeconds
                    delayValueText.text = "${it.celebrationDelaySeconds}s"
                    
                    // Display IP address if available
                    if (!it.ipAddress.isNullOrBlank()) {
                        ipAddressText.text = "IP: ${it.ipAddress}"
                        ipAddressText.visibility = View.VISIBLE
                    } else {
                        ipAddressText.visibility = View.GONE
                    }
                }
            }
        }
    }
    
    private fun checkPermissionsAndScan() {
        val permissions = if (Build.VERSION.SDK_INT >= Build.VERSION_CODES.S) {
            arrayOf(
                Manifest.permission.BLUETOOTH_SCAN,
                Manifest.permission.BLUETOOTH_CONNECT,
                Manifest.permission.ACCESS_FINE_LOCATION
            )
        } else {
            arrayOf(
                Manifest.permission.BLUETOOTH,
                Manifest.permission.BLUETOOTH_ADMIN,
                Manifest.permission.ACCESS_FINE_LOCATION
            )
        }
        
        val needsPermission = permissions.any {
            ActivityCompat.checkSelfPermission(this, it) != PackageManager.PERMISSION_GRANTED
        }
        
        if (needsPermission) {
            permissionLauncher.launch(permissions)
        } else {
            startScan()
        }
    }
    
    private fun startScan() {
        if (!viewModel.bluetoothManager.isBluetoothSupported()) {
            Toast.makeText(this, "Bluetooth not supported", Toast.LENGTH_LONG).show()
            return
        }
        
        if (!viewModel.bluetoothManager.isBluetoothEnabled()) {
            Toast.makeText(this, "Please enable Bluetooth", Toast.LENGTH_LONG).show()
            return
        }
        
        scanButton.isEnabled = false
        viewModel.bluetoothManager.startDiscovery()
    }
    
    private fun sendConfiguration() {
        val ssid = wifiSsidInput.text?.toString() ?: ""
        val password = wifiPasswordInput.text?.toString() ?: ""
        val selectedPosition = teamSpinner.selectedItemPosition
        val teamAbbr = TeamData.teams[selectedPosition].first
        val delaySeconds = delaySeekBar.progress
        
        if (ssid.isBlank()) {
            wifiSsidInput.error = "WiFi SSID required"
            return
        }
        
        configProgressBar.visibility = View.VISIBLE
        sendConfigButton.isEnabled = false
        viewModel.sendConfiguration(ssid, password, teamAbbr, delaySeconds)
    }
    
    private fun sendTestGoal() {
        Toast.makeText(this, "Sending test goal...", Toast.LENGTH_SHORT).show()
        viewModel.sendTestGoal()
    }
    
    private fun registerBluetoothReceiver() {
        val filter = IntentFilter().apply {
            addAction(BluetoothDevice.ACTION_FOUND)
            addAction(BluetoothAdapter.ACTION_DISCOVERY_FINISHED)
        }
        if (Build.VERSION.SDK_INT >= Build.VERSION_CODES.TIRAMISU) {
            registerReceiver(bluetoothReceiver, filter, RECEIVER_EXPORTED)
        } else {
            registerReceiver(bluetoothReceiver, filter)
        }
    }
    
    override fun onResume() {
        super.onResume()
        // Re-check for GoalStick when returning from Bluetooth settings
        if (viewModel.bluetoothManager.connectionState.value is BluetoothManager.ConnectionState.Disconnected) {
            autoConnectOrPrompt()
        }
    }
    
    override fun onDestroy() {
        super.onDestroy()
        unregisterReceiver(bluetoothReceiver)
        viewModel.bluetoothManager.stopDiscovery()
    }
}

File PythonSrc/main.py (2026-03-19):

import logging
import logging.handlers
import signal
import subprocess
import sys
import time
import argparse
from pathlib import Path
from StickCheck import (
    StickCheckScheduler, 
    SchedulerConfig,
    BluetoothPairing,
    BluetoothConfig,
    BluetoothServer,
    BluetoothServerConfig,
    BluetoothCommandServer,
    LEDController,
    LEDConfig,
    ConfigStore,
    PairingStatus,
    ButtonHandler,
    ButtonConfig,
    factory_reset,
    check_for_updates,
    update_and_restart,
    NetworkWatchdog,
    NetworkWatchdogConfig,
    StatusLED,
    DeviceState,
    is_wifi_configured
)

def setup_logging():
    """Set up logging with rotating file handler (weekly rotation, keep 4 weeks)."""
    log_dir = Path("/var/log/goalstick")
    log_dir.mkdir(parents=True, exist_ok=True)
    log_file = log_dir / "goalstick.log"
    
    formatter = logging.Formatter("%(asctime)s [%(levelname)s] %(name)s: %(message)s")
    
    # Rotating file handler - rotate weekly, keep 4 backups
    file_handler = logging.handlers.TimedRotatingFileHandler(
        log_file,
        when="W0",  # Rotate on Monday
        interval=1,
        backupCount=4,
        encoding="utf-8"
    )
    file_handler.setFormatter(formatter)
    file_handler.setLevel(logging.INFO)
    
    # Console handler for systemd/journald
    console_handler = logging.StreamHandler()
    console_handler.setFormatter(formatter)
    console_handler.setLevel(logging.INFO)
    
    # Configure root logger
    root_logger = logging.getLogger()
    root_logger.setLevel(logging.INFO)
    root_logger.addHandler(file_handler)
    root_logger.addHandler(console_handler)
    
    # Silence noisy httpx logging
    logging.getLogger("httpx").setLevel(logging.WARNING)
    logging.getLogger("httpcore").setLevel(logging.WARNING)

setup_logging()

log = logging.getLogger(__name__)

scheduler = None
button_handler = None
network_watchdog = None
status_led = None
bt_command_server = None
pairing_in_progress = False
factory_reset_enabled = False
service_start_time = None

def signal_handler(sig, frame):
    print("\nShutting down gracefully...")
    if button_handler:
        button_handler.stop()
    if network_watchdog:
        network_watchdog.stop()
    if status_led:
        status_led.stop()
    if scheduler:
        scheduler.stop()
    sys.exit(0)

def setup_button_handler(config: SchedulerConfig):
    global pairing_in_progress, factory_reset_enabled, service_start_time
    import time
    
    service_start_time = time.time()
    
    def on_button_hold():
        global pairing_in_progress, bt_command_server
        if pairing_in_progress:
            log.info("Pairing already in progress, ignoring button hold")
            return
        
        pairing_in_progress = True
        log.info("Button held (3s) - initiating Bluetooth pairing...")
        try:
            # Stop background BT server to free up the channel
            if bt_command_server and bt_command_server.is_running():
                log.info("Stopping background Bluetooth server for pairing mode...")
                bt_command_server.stop()
                time.sleep(1)  # Give it time to release the socket
            
            run_pairing_mode(config)
        finally:
            pairing_in_progress = False
            # Restart background BT server after pairing
            if bt_command_server:
                log.info("Restarting background Bluetooth server...")
                bt_command_server.start()
    
    def on_factory_reset():
        global factory_reset_enabled, service_start_time
        
        # Prevent factory reset within first 60 seconds of service start
        # This prevents accidental resets from stuck buttons or floating GPIO pins during boot
        elapsed_since_start = time.time() - service_start_time
        if elapsed_since_start < 60:
            log.warning(f"Factory reset blocked - service started only {elapsed_since_start:.1f}s ago (minimum 60s required)")
            log.warning("This prevents accidental resets during boot. Wait and try again.")
            return
        
        if not factory_reset_enabled:
            log.warning("Factory reset triggered but not yet enabled - enabling now")
            log.warning("Release button and hold again for 10s to confirm factory reset")
            factory_reset_enabled = True
            return
        
        log.warning("Button held (10s) - initiating FACTORY RESET...")
        if factory_reset(led_controller=scheduler.led_controller if scheduler else None):
            log.info("Factory reset complete - rebooting...")
            subprocess.run(["sudo", "reboot"], capture_output=True)
        else:
            log.error("Factory reset failed")
    
    btn_config = ButtonConfig(
        gpio_pin=config.pairing_button_pin,
        hold_time=config.pairing_button_hold_time,
        long_hold_time=config.factory_reset_hold_time
    )
    handler = ButtonHandler(config=btn_config)
    
    # Check initial button state before setting up callbacks
    # This helps detect stuck buttons or floating GPIO pins
    try:
        import RPi.GPIO as GPIO
        GPIO.setmode(GPIO.BCM)
        GPIO.setup(config.pairing_button_pin, GPIO.IN, pull_up_down=GPIO.PUD_UP)
        initial_state = GPIO.input(config.pairing_button_pin)
        if initial_state == GPIO.LOW:  # Button pressed at startup
            log.warning(f"WARNING: Button on GPIO {config.pairing_button_pin} is PRESSED at startup!")
            log.warning("This may indicate a stuck button or floating GPIO pin.")
            log.warning("Factory reset is DISABLED for 60 seconds to prevent accidental reset.")
        else:
            log.info(f"Button on GPIO {config.pairing_button_pin} is in normal state (released)")
    except Exception as e:
        log.debug(f"Could not check initial button state: {e}")
    
    handler.set_on_hold(on_button_hold)
    handler.set_on_long_hold(on_factory_reset)
    
    if handler.start():
        log.info(f"Button handler started on GPIO {config.pairing_button_pin}")
        log.info(f"  - Hold {config.pairing_button_hold_time}s for pairing mode")
        log.info(f"  - Hold {config.factory_reset_hold_time}s for factory reset")
        log.info(f"  - Factory reset requires 60s uptime + double confirmation")
        return handler
    else:
        log.warning("Button handler could not start - pairing via button disabled")
        return None
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

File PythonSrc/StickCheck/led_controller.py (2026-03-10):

import serial
import json
import logging
from pathlib import Path
from typing import List, Optional
from dataclasses import dataclass

log = logging.getLogger(__name__)


@dataclass
class LEDConfig:
    serial_port: str = "/dev/serial0"  # Default UART on Raspberry Pi
    baud_rate: int = 115200
    timeout: float = 1.0


class LEDController:
    def __init__(self, config: LEDConfig = None, team_colors_path: str = None):
        self.config = config or LEDConfig()
        self._serial: Optional[serial.Serial] = None
        self._team_colors: dict = {}
        self._load_team_colors(team_colors_path)
    
    def _load_team_colors(self, path: str = None) -> None:
        if path is None:
            # Default to team_colors.json in project root
            path = Path(__file__).parent.parent / "team_colors.json"
        else:
            path = Path(path)
        
        try:
            with open(path, 'r') as f:
                self._team_colors = json.load(f)
            log.info(f"Loaded colors for {len(self._team_colors)} teams")
        except FileNotFoundError:
            log.error(f"Team colors file not found: {path}")
            self._team_colors = {}
        except json.JSONDecodeError as e:
            log.error(f"Invalid JSON in team colors file: {e}")
            self._team_colors = {}
    
    def connect(self) -> bool:
        try:
            self._serial = serial.Serial(
                port=self.config.serial_port,
                baudrate=self.config.baud_rate,
                bytesize=serial.EIGHTBITS,
                parity=serial.PARITY_NONE,
                stopbits=serial.STOPBITS_ONE,
                timeout=self.config.timeout
            )
            log.info(f"Connected to ESP32 on {self.config.serial_port}")
            return True
        except serial.SerialException as e:
            log.error(f"Failed to connect to ESP32: {e}")
            return False
    
    def disconnect(self) -> None:
        if self._serial and self._serial.is_open:
            self._serial.close()
            log.info("Disconnected from ESP32")
    
    def is_connected(self) -> bool:
        return self._serial is not None and self._serial.is_open
    
    def get_team_colors(self, team_abbr: str) -> List[str]:
        colors = self._team_colors.get(team_abbr.upper(), [])
        if not colors:
            log.warning(f"No colors found for team: {team_abbr}")
        return colors
    
    def _send_command(self, command: str, retry: bool = True) -> bool:
        if not self.is_connected():
            log.warning("Not connected to ESP32, attempting to connect...")
            if not self.connect():
                return False
        
        try:
            # Ensure command ends with newline
            if not command.endswith('\n'):
                command += '\n'
            
            self._serial.write(command.encode('utf-8'))
            self._serial.flush()
            log.debug(f"Sent command: {command.strip()}")
            return True
        except (serial.SerialException, OSError) as e:
            log.error(f"Failed to send command: {e}")
            # Disconnect and retry once on I/O error
            self.disconnect()
            if retry:
                log.info("Reconnecting and retrying command...")
                return self._send_command(command, retry=False)
            return False
    
    def celebrate(self, team_abbr: str) -> bool:
        colors = self.get_team_colors(team_abbr)
        if not colors:
            log.error(f"Cannot celebrate: no colors for team {team_abbr}")
            return False
        
        # Format: C:RRGGBB,RRGGBB,...
        color_string = ",".join(colors)
        command = f"C:{color_string}"
        
        log.info(f"Triggering celebration for {team_abbr}: {command}")
        return self._send_command(command)
    
    def idle(self) -> bool:
        log.info("Sending idle command to ESP32")
        return self._send_command("I")
    
    def ping(self, timeout: float = 2.0) -> bool:
        if not self.is_connected():
            log.warning("Not connected to ESP32, attempting to connect...")
            if not self.connect():
                return False
        
        try:
            # Clear any pending data in buffer (ESP32 boot messages)
            self._serial.reset_input_buffer()
            
            # Send ping command
            self._serial.write(b"P\n")
            self._serial.flush()
            
            # Wait for PONG response
            original_timeout = self._serial.timeout
            self._serial.timeout = timeout
            
            try:
                # Read response, handling potential garbage bytes from ESP32 boot
                raw_response = self._serial.readline()
                try:
                    response = raw_response.decode('utf-8', errors='ignore').strip()
                except:
                    response = ""
                
                if "PONG" in response:
                    log.info("ESP32 health check passed")
                    return True
                else:
                    log.warning(f"ESP32 unexpected response: {response}")
                    return False
            finally:
                self._serial.timeout = original_timeout
                
        except serial.SerialException as e:
            log.error(f"ESP32 health check failed: {e}")
            return False
        except Exception as e:
            log.error(f"ESP32 health check error: {e}")
            return False
    
    def __enter__(self):
        self.connect()
        return self
    
    def __exit__(self, exc_type, exc_val, exc_tb):
        self.disconnect()
        return False

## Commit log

2026-01-28 Add automated scheduler for NHL goal monitoring
    - Implement StickCheckScheduler with daily execution during hockey season
    - Add smart sleep management (wakes before game start)
    - Add 0.5 second interval checking during live games
    - Improve scorekeeper API efficiency and error handling
    - Add retry logic with exponential backoff
    - Add comprehensive configuration options
    - Update README with usage documentation
    - Add MIT license
    - Modernize Python classes (remove unnecessary object inheritance)
    [main.py, scheduler.py, scorekeeper.py]
2026-01-31 Add ESP32 LED controller, Bluetooth pairing, and button support
    - Add LEDController for serial communication with ESP32
    - Add team_colors.json with all NHL team color definitions
    - Add ConfigStore for persistent team configuration (~/.goalstick/config.json)
    - Add BluetoothPairing with LED status feedback (blue/white/red)
    - Add ButtonHandler for GPIO press-and-hold pairing trigger
    - Add ESP32.md with firmware protocol documentation
    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
2026-01-31 Fix ESP32 pin assignments for Serial2 and LED data
    - Update ESP32 firmware to use Serial2 on GPIO 16 (RX) for Pi communication
    - Move LED data pin from GPIO 16 to GPIO 4 to avoid conflict
    - Add debug logging for received commands
    - Update ESP32.md and README.md with correct wiring diagrams
    [hockey_stick_light_controller.ino]
2026-01-31 Add ESP32 health check with ping/pong and auto-reset capability
    - Add ping command (P) to ESP32 firmware, responds with PONG
    - Add ping() method to LEDController for health check
    - Add ESP32Reset module for hardware reset via GPIO 27 → EN pin
    - Add _ensure_esp32_ready() to scheduler with retry logic
    - Automatically reset ESP32 if ping fails before game monitoring
    - Update ESP32.md and README.md with new command and wiring
    [esp32_reset.py, hockey_stick_light_controller.ino, led_controller.py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]
2026-01-31 Add unit test suite with pytest
    - Add tests directory with pytest configuration
    - Add 69 unit tests covering:
    - ConfigStore: persistence, save/load, team management
    - LEDController: serial communication, ping, celebrate, idle
    - HockeySeasonDetector: all months and edge cases
    - ESP32Reset: GPIO setup, reset, cleanup
    - ButtonHandler: GPIO, press detection, callbacks
    - SchedulerConfig: default and custom values
    - Add pytest and pytest-cov as dev dependencies
    - Move RPi.GPIO to optional 'rpi' dependency group
    - Fix Python version requirement to >=3.9
    - Configure setuptools to only include StickCheck package
    [test_button_handler.py, test_config_store.py, test_esp32_reset.py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]
2026-02-01 Add Android app codebase
    - Create Android project structure with Gradle build system
    - Set up Kotlin source with MainActivity
    - Add Android manifest and resources
    - Configure Material3 theme
    - Add README with build instructions
2026-02-01 Add Android app Bluetooth configuration and Pi-side server
    Android App:
    - Add Bluetooth permissions to manifest
    - Create BluetoothManager for device discovery and connection
    - Create MainActivity with scan, connect, and configuration UI
    - Add WiFi SSID/password input fields
    - Add NHL team selection spinner with all 32 teams
    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
2026-02-01 Add Gradle wrapper for command-line builds
    - Add gradlew and gradlew.bat scripts
    - Add gradle-wrapper.jar and properties
    - Enables building APK without Android Studio:
    ./gradlew assembleDebug
2026-02-01 Add Makefile for building and testing
    Android targets:
    - android-build: Build debug APK
    - android-release: Build release APK
    - android-install: Install APK to device
    - android-clean: Clean build artifacts
    Python targets:
    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
2026-02-01 Fix Bluetooth server socket binding error
    - Add _get_local_bluetooth_address() to get adapter MAC address
    - Use hciconfig or bluetoothctl to find local BT address
    - Bind socket to explicit address instead of empty string
    - Fixes 'bad bluetooth address' error on Pi
    [bluetooth_server.py]
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2026-02-01 Fix Bluetooth discoverability with hciconfig piscan
    - Use 'hciconfig hci0 piscan' for reliable discoverability
    - Ensure adapter is up before configuring
    - Verify PSCAN and ISCAN flags are set
    - Log warning if discoverability check fails
    [bluetooth_server.py]
2026-02-02 Fix Android 13+ broadcast receiver for Bluetooth discovery
    - Add RECEIVER_EXPORTED flag for Android 13+ (Tiramisu)
    - Fixes broadcast receiver not receiving ACTION_FOUND events
    [MainActivity.kt]
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2026-02-02 Fix invalid import in bluetooth_server.py
    [bluetooth_server.py]
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2026-02-02 Improve Android app UX for paired devices
    - Show paired devices on app startup without requiring scan
    - Provide clearer error message when Pi is not in pairing mode
    [MainActivity.kt]
2026-02-02 Fix sdptool to use sudo for SPP service registration
    [bluetooth_server.py]
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2026-02-02 Auto-connect to GoalStick if paired, prompt for Bluetooth settings if not
    - Replace device list with auto-connect behavior
    - If GoalStick is paired, automatically connect on app launch
    - If not paired, show button to open Bluetooth settings
    - Re-check on resume when returning from settings
    [MainActivity.kt]
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2026-02-02 Fix test_goal celebration - pass team_abbr to celebrate()
    [bluetooth_server.py]
2026-02-03 Add factory reset (10s hold) and auto-update functionality
    Factory Reset (10s button hold):
    - Clears all Bluetooth pairings
    - Removes WiFi configuration
    - Deletes GoalStick config
    - Reboots device
    Auto-Update:
    - Daily check for GoalStick code updates (git pull)
    - Weekly system security updates (Sundays)
    - Updates applied at 8 AM daily check
    [auto_update.py, button_handler.py, factory_reset.py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]
2026-02-03 Make service bulletproof with watchdog and restart policies
    Service file:
    - StartLimitBurst=5 in 300s prevents restart loops
    - WatchdogSec=60 - systemd kills if no ping in 60s
    - MemoryMax=256M, CPUQuota=50% - resource limits
    Scheduler:
    - Background thread pings systemd watchdog every 30s
    - Notifies READY=1 on start, STOPPING=1 on stop
    - Added sdnotify dependency
    [scheduler.py]
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2026-02-03 Add network watchdog - reboots if no connectivity for 5 minutes
    - Pings 8.8.8.8 and 1.1.1.1 every 60 seconds
    - After 5 consecutive failures (5 minutes), triggers reboot
    - Runs as background thread during normal operation
    - Logs warnings on each failure, critical on reboot
    [main.py, network_watchdog.py]
2026-02-03 Add read-only filesystem support for SD card protection
    - setup-readonly.sh script configures overlayfs
    - Persistent storage for config, WiFi, Bluetooth at /persistent/
    - Logs go to tmpfs (lost on reboot)
    - Auto-updates handle overlay: disable, reboot, update, re-enable, reboot
    - Helper commands: goalstick-status, goalstick-rw, goalstick-ro
    - make deploy-readonly target
    - Script is idempotent (skips if already configured)
    - Updated README with documentation
    [auto_update.py, scheduler.py]
2026-02-03 Add RGB status LED for device state indication
    - StatusLED class with GPIO control for RGB LED
    - States: booting, ready, waiting, game_live, pairing, error, no_network, updating
    - Patterns: solid, slow blink, fast blink
    - Integrated into scheduler for automatic state updates
    - Default pins: GPIO 22 (red), 23 (green), 24 (blue)
    - Updated README with wiring and state documentation
    [main.py, scheduler.py, status_led.py]
2026-02-03 Simplify status LED - off during normal operation
    LED only lights up for special states:
    - Yellow: Booting
    - Blue blink: Pairing mode
    - Cyan blink: Updating
    - Red: Error
    - Red blink: No network
    LED is OFF during normal operation (ready, waiting, game live)
    [scheduler.py, status_led.py]
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2026-02-05 Fix ESP32 wiring documentation - correct Serial2 pins
    - ESP32 uses GPIO 16 (RX2) and GPIO 17 (TX2) for Serial2
    - Added LED strip wiring section (GPIO 4 for data)
    [hockey_stick_light_controller.ino]
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2026-02-05 Fix factory reset and Android app connection handling
    Bug 1: Factory reset now clears Bluetooth cache directory directly
    - Removes paired device directories from /var/lib/bluetooth
    - Restarts Bluetooth service after clearing
    Bug 2: Android app handles connection failure gracefully
    - Shows helpful message when GoalStick is paired but not in config mode
    - Prompts user to press button for 3 seconds to enter pairing mode
    - Provides Retry button instead of showing all nearby devices
    [MainActivity.kt, factory_reset.py]
2026-02-05 Fix Bluetooth audio profile issue - disable A2DP/AVRCP plugins
    - Set device class to pure Computer (0x000100) without service bits
    - Add BlueZ config to disable a2dp and avrcp plugins
    - Prevents Android from treating GoalStick as a headset
    - Updated firstboot-setup.sh and README with instructions
    [bluetooth_server.py]
2026-02-05 Use LED strip for status indication instead of separate RGB LED
    - StatusLED now sends colors to LED strip via LED controller
    - Removed GPIO pin configuration for separate RGB LED
    - Fixed Capitals team color (CF0A2C instead of E51937) - pure red without green
    - Updated README to reflect LED strip status indicator
    - Updated tests for new Capitals color
    [main.py, scheduler.py, status_led.py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]
2026-02-05 Fix status LED spamming idle commands when in OFF state
    When state is OFF, don't send any commands to LED strip - just sleep.
    This allows celebrations and other LED commands to work properly.
    [status_led.py]
2026-02-05 Fix WiFi setup and Bluetooth reconnection after service restart
    1. WiFi setup fix: When WiFi is configured via Bluetooth pairing,
    the service now detects this and restarts to pick up the new config
    and check for games.
    2. Bluetooth reconnection fix: Added BluetoothCommandServer that runs
    in the background during normal operation. This allows the Android
    app to send commands (test_goal, get_config, etc.) even after the
    service restarts. The server registers an SDP service and listens
    on channel 1 for SPP connections.
    [bluetooth_server.py, main.py]
2026-02-05 Fix suspend function call in DeviceAdapter click handler
    [MainActivity.kt]
2026-02-06 Fix ESP32 serial reconnection on I/O error
    When serial write fails with I/O error, disconnect and retry once
    to recover from stale connections
    [led_controller.py]
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2026-02-06 Add KiCad project files and update design doc with KiCad instructions
    [GoalStick.kicad_sch]
2026-02-06 Add KiCad PCB design for GoalStick carrier board
    [GoalStick-B_Cu.gbr, GoalStick-B_Mask.gbr, GoalStick-B_Paste.gbr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]
2026-02-23 Add DEPLOYMENT.md, update ESP32 firmware for XIAO ESP32C3, add KiCad footprints
    - Add DEPLOYMENT.md with hands-free installation instructions
    - Update README.md to link to deployment guide
    - Update ESP32 firmware for XIAO ESP32C3 (Serial1, pin mappings, startup delay)
    - Add custom KiCad footprints for XIAO and Pi Zero 2W
    - Update KiCad schematic and PCB layout
    [GoalStick.kicad_pcb, GoalStick.kicad_sch]
2026-02-23 Fix missing time import causing service crash
    [main.py]
2026-02-26 Add factory reset safeguards to prevent accidental resets
    - Add 60-second startup delay before factory reset is enabled
    - Require double confirmation (enable, then confirm) for factory reset
    - Check and log initial button state at startup to detect stuck buttons
    - Prevents accidental resets from floating GPIO pins or stuck buttons during boot
    [main.py]
2026-03-01 Fix Bluetooth pairing: stop background server first, retry hci0 up
    [bluetooth_server.py, main.py]
2026-03-02 Update .gitignore and remove generated/local KiCad files from repo
    Fixed bad routes on the Pi to ESP32 serial connections, updated SMD pads on the ESP32 to drilled holes.
    [GoalStick-B_Cu.gbr, GoalStick-B_Mask.gbr, GoalStick-B_Paste.gbr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]
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2026-03-10 Fix Bluetooth adapter bring-up on Pi Zero W 2
    - Add rfkill unblock bluetooth before hciconfig up
    - Use bluetoothctl power on as additional method
    - Add delays between commands for reliability
    [bluetooth_server.py]
2026-03-10 Fix Bluetooth adapter bring-up in background command server
    - Add rfkill unblock bluetooth
    - Add bluetoothctl power on
    - Add delays for reliability on Pi Zero W 2
    [bluetooth_server.py]
2026-03-10 Fix ESP32 blocking on USB Serial connection
    Removed 'while (!Serial)' which blocked startup until USB was connected.
    ESP32 now starts immediately and listens on Serial1 (Pi UART) without USB.
    [hockey_stick_light_controller.ino]
2026-03-10 Fix ESP32 ping to handle boot garbage bytes
    - Use errors='ignore' when decoding serial response
    - Check for 'PONG' substring instead of exact match
    - Prevents health check failures from ESP32 boot messages
    [led_controller.py]
2026-03-10 Fix team dropdown text color for dark mode
    - Add custom spinner layouts with theme-aware text colors
    - Use ?attr/colorOnSurface for text that adapts to light/dark mode
    - Add spinner background drawable with proper styling
    [MainActivity.kt]
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2026-03-18 Update LED count, celebration pattern, and add IP display
    ESP32 changes:
    - Change LED count from 300 to 100 for shorter stick
    - Blink only first 10 LEDs during celebration start
    - Fix chase pattern to divide LEDs evenly by color count (33 per color for 3-color teams)
    Android app changes:
    - Add IP address display below status text
    - Parse ip_address from config response
    - Show IP when WiFi is configured
    Python backend changes:
    - Add _get_ip_address() to get wlan0 IP
    - Include ip_address in config responses for both pairing and background servers
    [MainActivity.kt, bluetooth_server.py, hockey_stick_light_controller.ino]
2026-03-18 Fix: Add missing _get_ip_address method to BluetoothCommandServer
    - BluetoothCommandServer was calling _get_ip_address() but didn't have the method
    - Caused 'Failed to send configuration' error after factory reset
    - Added _get_ip_address() method to match BluetoothServer implementation
    [bluetooth_server.py]
2026-03-18 Fix blink phase to show all LEDs divided by team colors
    - Blink phase now displays all 100 LEDs, not just first 10
    - LEDs divided equally by team color count (33 per color for 3-color teams)
    - Example: Capitals score = 33 red, 33 blue, 33 white LEDs blinking
    [hockey_stick_light_controller.ino]
2026-03-18 Add ESP32 debug logging and safety checks
    - Add safety check to prevent celebration with no colors set
    - Log unknown commands to help debug serial communication issues
    - Should help diagnose blue blink issue on idle commands
    [hockey_stick_light_controller.ino]
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2026-03-19 Use hostname as Bluetooth device name
    - Bluetooth device name now uses system hostname (e.g., GoalStick001)
    - Allows multiple GoalSticks to be distinguished without manual config
    - Falls back to hostname in BluetoothServer, BluetoothPairing, and scheduler
    - Makes testing multiple devices easier without resetting Bluetooth pairings
    [bluetooth_pairing.py, bluetooth_server.py, scheduler.py]
2026-03-19 Add LED indicators for factory reset and boot completion
    - Flash red (C:FF0000) before factory reset to confirm command received
    - Flash yellow/amber (C:AAAA00) on boot completion to indicate system ready
    - Both indicators show for 2 seconds before continuing
    - Helps user understand system state during critical operations
    [factory_reset.py, main.py]
2026-03-27 Fix Bluetooth agent D-Bus path not released between pairing sessions
    Previous stop() only quit the GLib mainloop, leaving the D-Bus object
    path /com/goalstick/agent registered. On the next pairing attempt,
    AutoPairAgent() would fail with "already a handler", crashing the agent
    thread silently and leaving BlueZ with no agent to accept pairing —
    causing Android to reject the connection.
    Fix: stop() now calls UnregisterAgent() and remove_from_connection()
    to fully release the path. start() also waits for the thread to confirm
    successful registration before returning, so failures surface immediately.
    [bluetooth_agent.py]
2026-03-27 Fix Bluetooth connection by bypassing SSP authentication handshake
    bluetoothd rejects User Confirmation Requests internally (~500us) before
    the agent is ever invoked, because the default RFCOMM security level
    requires authentication that the headless Pi cannot complete via SSP.
    Fix both sides to agree on unauthenticated connections:
    - Android: createInsecureRfcommSocketToServiceRecord (no MITM required)
    - Pi: BT_SECURITY_LOW on RFCOMM server sockets (no auth/encryption needed)
    With both sides at security level LOW, the SSP handshake is skipped
    entirely and the RFCOMM connection is established directly.
    Also adds SecureConnections=off to BlueZ main.conf during deployment
    to prevent SC from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
    [bluetooth_server.py]
2026-03-27 Fix Bluetooth pairing and app connection flow
    - bluetooth_agent: move DBusGMainLoop init to module level (required for
    thread-safe D-Bus); register as DisplayYesNo so BlueZ calls
    RequestConfirmation on our agent instead of auto-rejecting internally;
    add verbose AGENT: logging to all methods for debugging
    - bluetooth_server: add btmgmt io-cap 1 to set HCI IO capability to match
    agent; update fallback bluetoothctl agent to DisplayYesNo
    - MainActivity: auto-connect to GoalStick by name (contains "goalstick" or
    "goalpi"), start in-app scan when not paired instead of opening Settings
    - bluetooth/BluetoothManager: use createInsecureRfcommSocketToServiceRecord
    to avoid MITM-required aut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
    [MainActivity.kt, bluetooth_agent.py, bluetooth_server.py]
2026-03-27 Replace Python D-Bus Bluetooth agent with bluetoothctl subprocess
    The Python dbus/GLib agent registered successfully but bluetoothd never
    called it — the GLib mainloop in a thread wasn't dispatching incoming D-Bus
    method calls fast enough for bluetoothd's 286μs internal timeout.
    Replace with a bluetoothctl subprocess: bluetoothctl handles BlueZ D-Bus
    wiring correctly in its own event loop, and is the same mechanism that
    works when run manually. Drains stdout in a thread to prevent blocking.
    [bluetooth_agent.py]
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2026-03-27 Set btmgmt io-cap to NoInputNoOutput before starting bluetoothctl agent
    bluetoothctl registers the D-Bus agent as NoInputNoOutput but doesn't
    update the HCI-level btmgmt io-cap, which can be stale (DisplayYesNo)
    from a previous session. This caused the Pi to advertise DisplayYesNo,
    triggering Numeric Comparison (confirm_hint=0) which NoInputNoOutput
    cannot respond to — resulting in a 33-second LMP timeout.
    Setting io-cap 3 first ensures Just Works (confirm_hint=1) is used,
    which bluetoothctl auto-confirms silently.
    [bluetooth_server.py]
2026-03-27 Remove futile btmgmt io-cap call; add explanatory comment
    Bluetoothd overrides btmgmt io-cap to KeyboardDisplay whenever any agent
    registers — the explicit io-cap 3 command had no effect. Added comment
    explaining the correct connection flow (app only, not Android Settings).
    [bluetooth_server.py]
2026-03-27 Remove Bluetooth agent to fix headless pairing
    Registering any D-Bus agent (Python or bluetoothctl subprocess) causes
    bluetoothd to override its IO capability to KeyboardDisplay (0x04). The
    Pi's BCM hardware actually transmits DisplayYesNo (0x01) in the HCI IO
    Capability Reply, creating a mismatch. bluetoothd then expects confirm_hint=0
    (Numeric Comparison) but receives confirm_hint=1 (Just Works) and immediately
    rejects in ~340μs without calling any agent.
    Without an agent, bluetoothd defaults to NoInputNoOutput — hardware sends
    NoInputNoOutput consistently — and auto-accepts Just Works (confirm_hint=1)
    connections from the app's createInsecureRfcommSocketToServiceRecord.
    Co-Authored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
    [bluetooth_server.py]
2026-04-26 Restart service after auto-update so new code takes effect
    Without the restart, the service kept running with stale code after a
    successful git pull + pip install, and the UPDATING LED blink (cyan)
    would continue for the entire duration of pip install (~minutes on Pi
    Zero) with no recovery until a manual reboot.
    [scheduler.py]
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2026-10-19 Fix Android app reliability and bump to 0.6.0
    Android
    - Newline-framed JSON reads with legacy bare-object fallback; requests
    serialized with a mutex and bounded by a 15s timeout
    - Preserve connection errors instead of overwriting them with Disconnected;
    surface server error messages in the UI
    - Auto-connect once per launch; remember last GoalStick by address and add
    a Reconnect button (insecure RFCOMM never bonds)
    - Fall back to RFCOMM channel 1 when the SDP record is missing
    - Fix scan button getting stuck, scanning state never clearing, Send
    Configuration staying disabled, and repeat success toasts not showing
    - Send WiFi credentials only when a password is entered
    - Replace ARI wi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
2026-10-20 Clear stale Bluetooth bonds when entering pairing mode
    The app connects over an insecure RFCOMM socket and never bonds, so the only
    way a bond reaches the stick is a user pairing it from Android's Bluetooth
    settings. Once the phone loses its copy of that link key, the controller
    rejects the phone with HCI_ERR_AUTH_FAILURE ("incorrect PIN or passkey")
    before the pairing server ever sees a connection, and only a factory reset
    could recover it.
    Pairing mode now removes every bonded device before the adapter is made
    discoverable. factory_reset reuses the same helper. The app's WiFi help text
    and the README tell users to connect through the app rather than pair in
    Android settings.
    Co-Authored-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
2026-10-20 Use `bluetoothctl devices Paired` to list bonds
    `bluetoothctl paired-devices` was removed in BlueZ 5.65 and the Pi runs
    5.82, where it fails with "Invalid command in menu main". The listing
    therefore always failed and no bond was ever removed, both in the new
    pairing-mode clearing and in the factory reset it was extracted from.
2026-10-20 Fall back to a scan when the remembered GoalStick cannot be reached
    The app already remembers the last stick and reconnects to it on launch,
    but a failed reconnect stopped at an error telling the user to hold the
    button for pairing mode. The background server is always connectable and
    discoverable, so that advice was wrong and nudged people towards pairing
    mode or Android's Bluetooth settings. Now a failed launch reconnect starts
    a scan, and the reconnect and no-devices messages say to check power and
    range instead.
    No Android test harness exists; verified by building the debug APK.
2026-10-21 Run the adapter classic-only so Android keeps the bond-free link
    With a stale bond removed, app connections still failed: the phone completed
    a non-bonding Just Works pairing (normal for an insecure RFCOMM socket) and
    encryption came up, but the Pi kernel then sent a BR/EDR SMP pairing request
    (cross-transport key derivation for LE). Android treated that as a bonding
    attempt on a link it asked to keep bond-free and dropped the ACL before the
    RFCOMM channel was up. btmon confirmed the SMP request came from the Pi and
    that disabling LE removes it; the full protocol then works.
    _ensure_adapter_up() now runs `btmgmt le off` once the adapter is up, since
    that is runtime state. `make deploy` writ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
